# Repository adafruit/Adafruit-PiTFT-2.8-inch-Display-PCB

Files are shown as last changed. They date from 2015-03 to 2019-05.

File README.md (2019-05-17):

# Adafruit PiTFT 2.8 inch LCD Display PCB
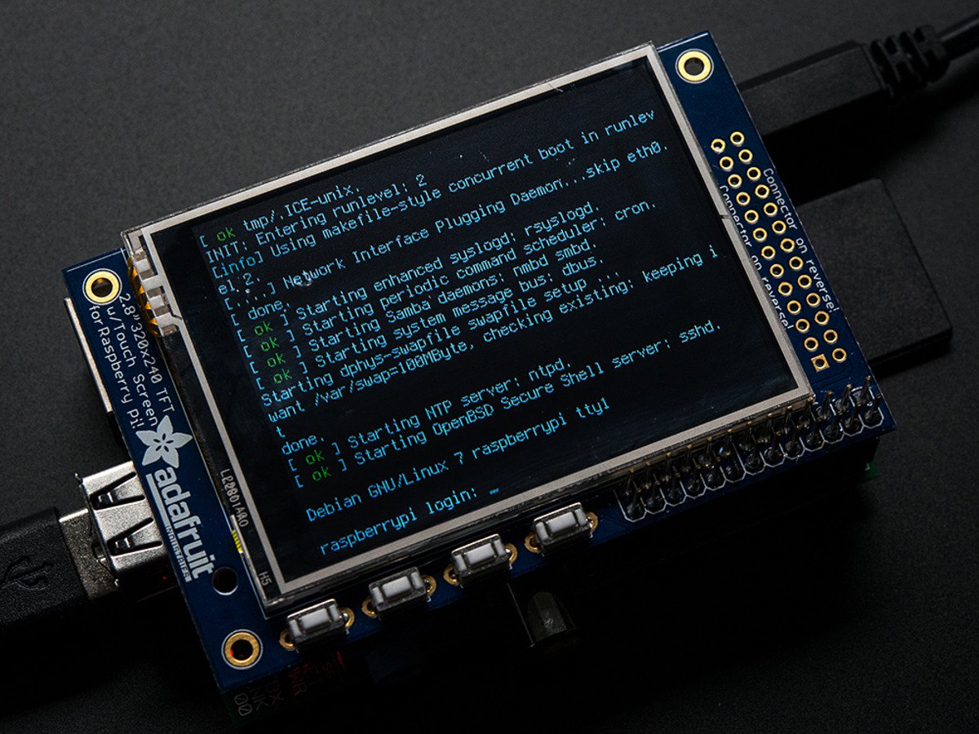
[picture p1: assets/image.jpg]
<a href="http://www.adafruit.com/products/1601"><br/>
Click here to purchase one from the Adafruit shop</a>

This display features a 2.8" LCD with 320x240 16-bit color pixels and a resistive touch overlay. The plate uses the high speed SPI interface on the Pi and can use the mini display as a console, X window port, displaying images or video etc. Best of all it plugs right in on top!

It's designed to fit nicely onto the Pi 1 Model A or B but also works OK with the Pi Zero, Pi 3, Pi 2 or Pi 1 Model A+ or B+ (any Pi with a 2x20 connector) as long as you don't mind the PCB overhangs the USB ports by 5mm, see the photos above. If you have a modern Pi with a 2x20 connector, you may want to grab a PiTFT 2.8" Plus which does not overhang

PCB files for Adafruit PiTFT 2.8 inch Resistive Touch Display. The format is EagleCAD schematic and board layout 
- https://www.adafruit.com/product/1601

### License

Adafruit invests time and resources providing this open source design, please support Adafruit and open-source hardware by purchasing products from [Adafruit](https://www.adafruit.com)!

All text above must be included in any redistribution

Designed by Limor Fried/Ladyada for Adafruit Industries.
Creative Commons Attribution/Share-Alike, all text above must be included in any redistribution. 
See license.txt for additional information.

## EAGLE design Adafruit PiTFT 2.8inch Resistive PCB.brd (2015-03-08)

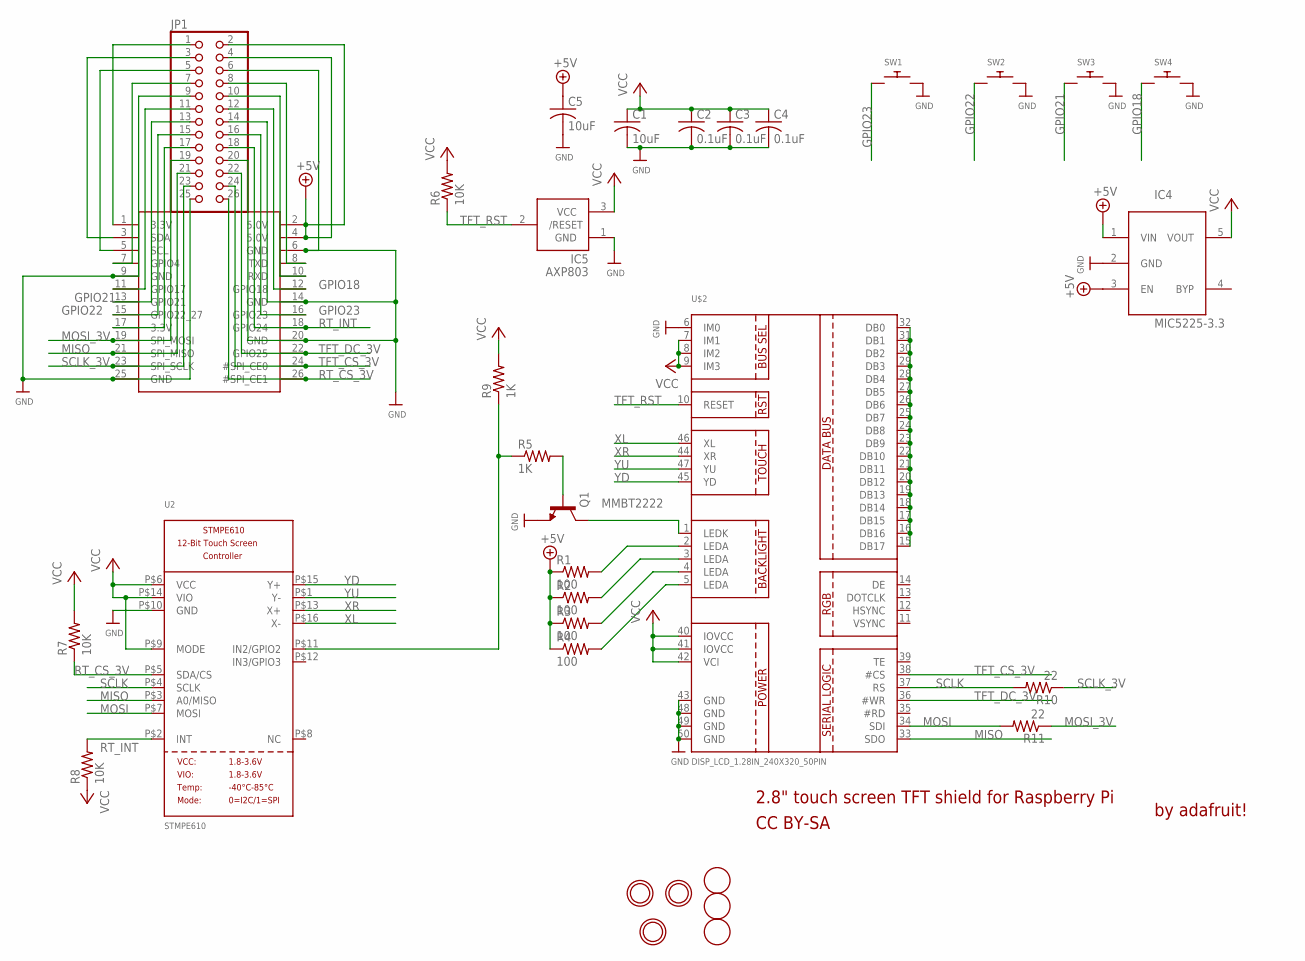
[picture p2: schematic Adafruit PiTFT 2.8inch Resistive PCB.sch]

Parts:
C1, C5: 10uF; C0805K
C2, C3, C4: 0.1uF; C0805K
IC4: MIC5225-3.3; SOT23-5L
IC5: AXP803; SOT23
JP1: HEADER-2X13; 2X13
Q1: MMBT2222; SOT23-BEC
R1, R2, R3, R4: 100; R0805
R5, R9: 1K; R0805
R6, R7, R8: 10K; R0805
R10, R11: 22; R0805
SW1, SW2, SW3, SW4: SWITCH_PUSHBUTTONEVQ-PE; TACT_PANA-EVQ
U2: STMPE610; QFN16_3MM
U$2: DISP_LCD_1.28IN_240X320_50PIN; TFT_2.83IN_240X320_50PIN
U$3: RASPBERRYPI_B_MODELB_V2; RASPBERRYPIV2_SHIELD
U$10, U$11, U$18: FIDUCIAL; FIDUCIAL_1MM
U$15, U$16, U$17: MOUNTINGHOLE2.5_THICK; MOUNTINGHOLE_2.5_PLATED_THICK

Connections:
3.3V: JP1.1, U$3.1 (3.3V)
3.3V@2: JP1.17, U$3.17 (3.3V)
+5V: C5.1, IC4.1 (VIN), IC4.3 (EN), JP1.2, JP1.4, R1.1, R2.1, R3.1, R4.1, U$3.2 (5.0V), U$3.4 (5.0V)
GND: C1.2, C2.2, C3.2, C4.2, C5.2, IC4.2 (GND), IC5.1 (GND), JP1.6, JP1.9, JP1.14, JP1.20, JP1.25, Q1.E, SW1.P$2, SW2.P$2, SW3.P$2, SW4.P$2, U2.P$10 (GND), U$2.6 (IM0), U$2.43 (GND), U$2.48 (GND), U$2.49 (GND), U$2.50 (GND), U$3.6 (GND), U$3.9 (GND), U$3.14 (GND), U$3.20 (GND), U$3.25 (GND)
GPIO18: JP1.12, SW4.P$1, U$3.12 (GPIO18)
GPIO21: JP1.13, SW3.P$1, U$3.13 (GPIO21)
GPIO22: JP1.15, SW2.P$1, U$3.15 (GPIO22_27)
GPIO23: JP1.16, SW1.P$1, U$3.16 (GPIO23)
MISO: JP1.21, U2.P$3 (A0/MISO), U$2.33 (SDO), U$3.21 (SPI_MISO)
MOSI: R11.2, U2.P$7 (MOSI), U$2.34 (SDI)
MOSI_3V: JP1.19, R11.1, U$3.19 (SPI_MOSI)
unnamed: Q1.C, U$2.1 (LEDK)
unnamed: R1.2, U$2.2 (LEDA)
unnamed: R2.2, U$2.3 (LEDA)
unnamed: R3.2, U$2.4 (LEDA)
unnamed: R5.1, R9.1, U2.P$11 (IN2/GPIO2)
unnamed: JP1.3, U$3.3 (SDA)
unnamed: JP1.5, U$3.5 (SCL)
unnamed: JP1.7, U$3.7 (GPIO4)
unnamed: U$2.15 (DB17), U$2.16 (DB16), U$2.17 (DB15), U$2.18 (DB14), U$2.19 (DB13), U$2.20 (DB12), U$2.21 (DB11), U$2.22 (DB10), U$2.23 (DB9), U$2.24 (DB8), U$2.25 (DB7), U$2.26 (DB6), U$2.27 (DB5), U$2.28 (DB4), U$2.29 (DB3), U$2.30 (DB2), U$2.31 (DB1), U$2.32 (DB0)
unnamed: R4.2, U$2.5 (LEDA)
unnamed: JP1.11, U$3.11 (GPIO17)
unnamed: Q1.B, R5.2
unnamed: JP1.10, U$3.10 (RXD)
unnamed: JP1.8, U$3.8 (TXD)
RT_CS_3V: JP1.26, R7.1, U2.P$5 (SDA/CS), U$3.26 (#SPI_CE1)
RT_INT: JP1.18, R8.2, U2.P$2 (INT), U$3.18 (GPIO24)
SCLK: R10.2, U2.P$4 (SCLK), U$2.37 (RS)
SCLK_3V: JP1.23, R10.1, U$3.23 (SPI_SCLK)
TFT_CS_3V: JP1.24, U$2.38 (#CS), U$3.24 (#SPI_CE0)
TFT_DC_3V: JP1.22, U$2.36 (#WR), U$3.22 (GPIO25)
TFT_RST: IC5.2 (/RESET), R6.1, U$2.10 (RESET)
VCC: C1.1, C2.1, C3.1, C4.1, IC4.5 (VOUT), IC5.3 (VCC), R6.2, R7.2, R8.1, R9.2, U2.P$6 (VCC), U2.P$9 (MODE), U2.P$14 (VIO), U$2.7 (IM1), U$2.8 (IM2), U$2.9 (IM3), U$2.40 (IOVCC), U$2.41 (IOVCC), U$2.42 (VCI)
XL: U2.P$16 (X-), U$2.46 (XL)
XR: U2.P$13 (X+), U$2.44 (XR)
YD: U2.P$15 (Y+), U$2.45 (YD)
YU: U2.P$1 (Y-), U$2.47 (YU)

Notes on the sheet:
2.8" touch screen TFT shield for Raspberry Pi
by adafruit!
CC BY-SA

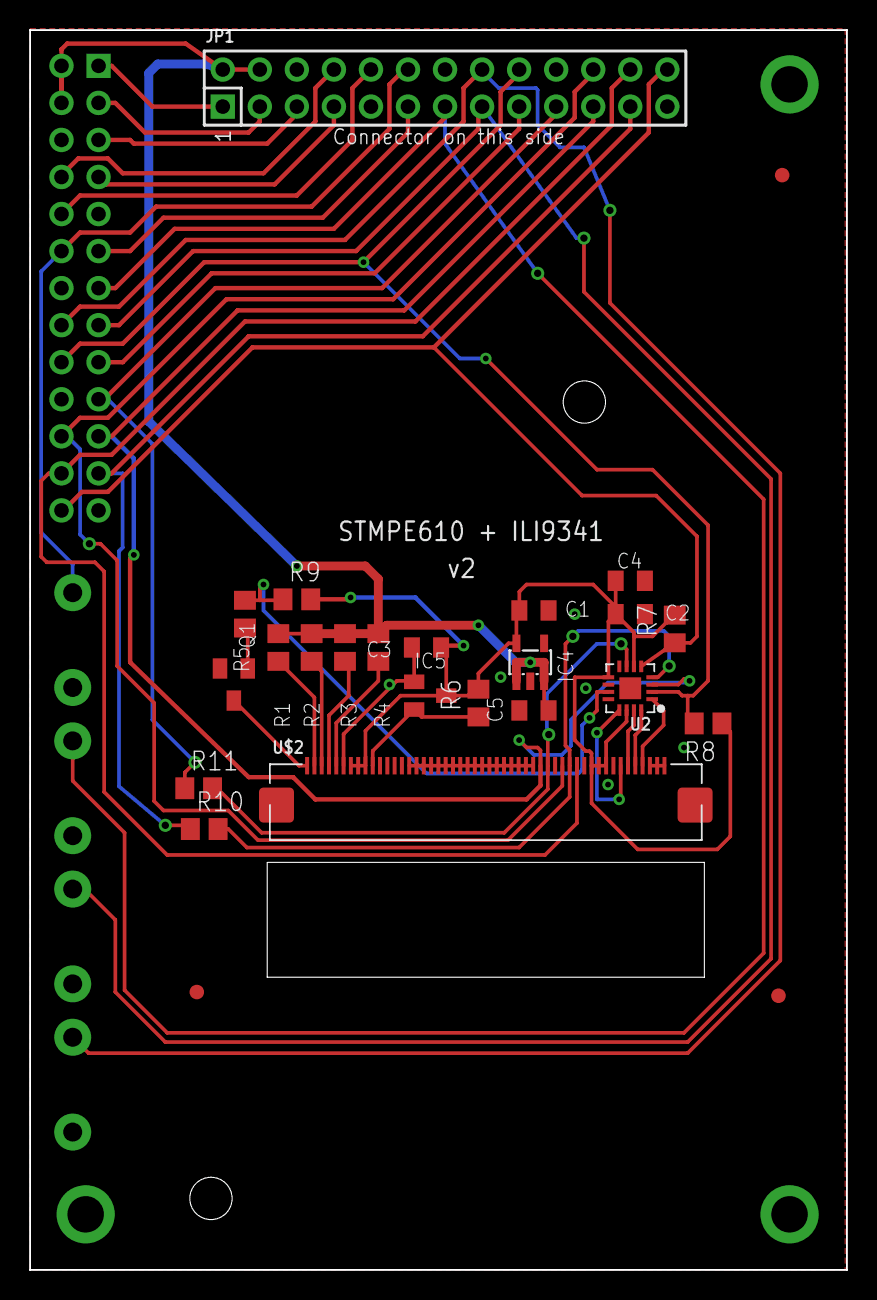
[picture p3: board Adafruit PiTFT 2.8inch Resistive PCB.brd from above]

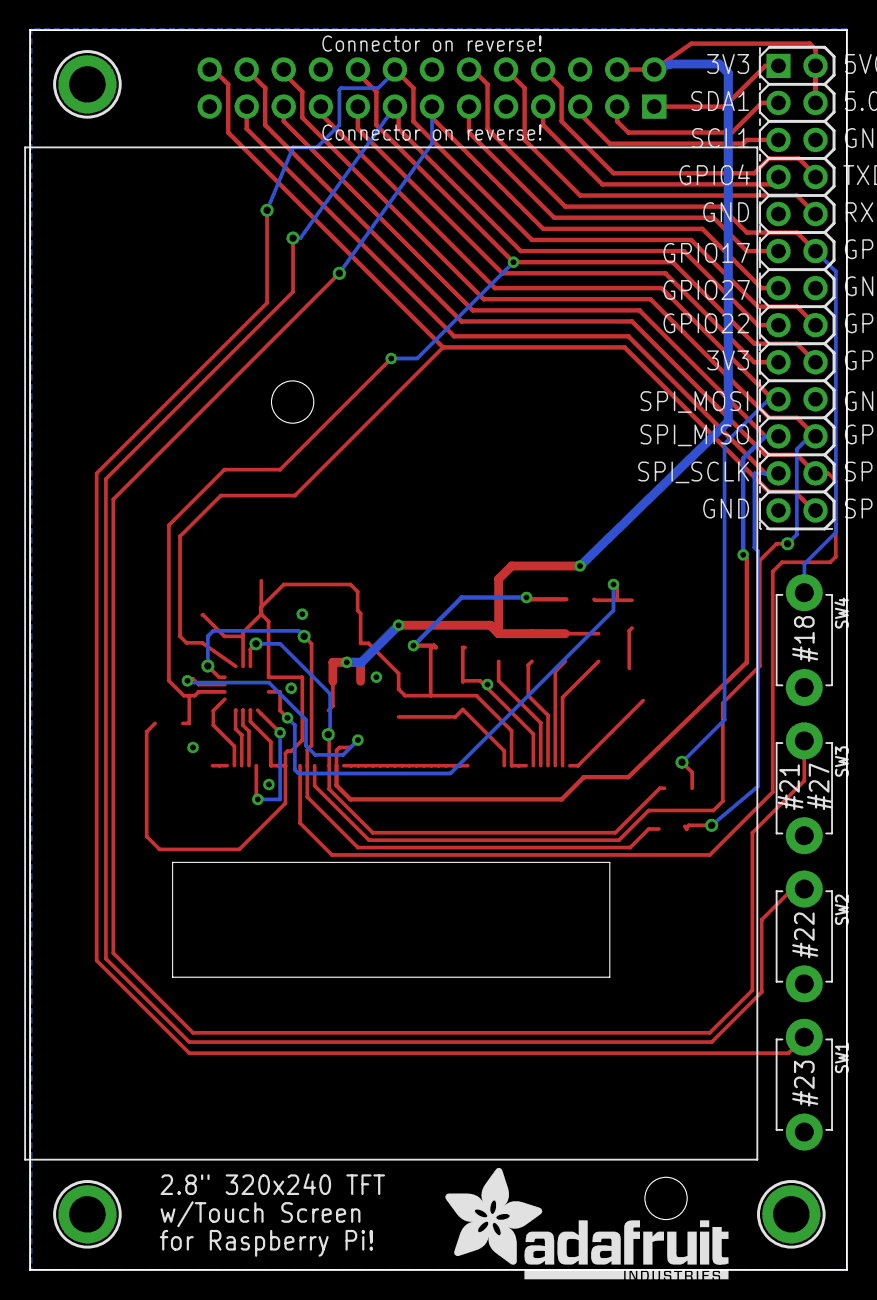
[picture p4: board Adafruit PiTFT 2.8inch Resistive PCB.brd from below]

Board: 2 copper layers, 56.0 x 85.0 mm, 34 parts (10 on the bottom side), 37 nets.

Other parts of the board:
U$23: ADAFRUIT_TEXT_20MM
